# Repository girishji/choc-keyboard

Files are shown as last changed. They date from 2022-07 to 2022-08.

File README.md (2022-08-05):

## Kailh Choc Keyboard with hotswap

A keyboard PCB for Kailh Choc low profile switches using KiCad. PCB has
soldering holes for Blackpill (STM32F401) and Adafruit IS31FL3731 breakout
board.

- Use 1.2mm thickness pcb (suitable for Choc 1350 hotswap sockets)
- Diodes are SOD-123 (1N4148)
- LED is SMD 6028 monochrome (you can get white ones from aliexpress). They are
  connected through charlieplex using IS31FL3731 LED driver (Adafruit's
  breakout board). 
- IS31FL3731 drives (PWM) LEDs at 8k Hz. This may cause audible buzz from the
  ceramic capacitors on board of Adafruit board when driven full power. To
  remove noise replace the 2 10uF capacitors on the Adafruit board with
  tantalum capacitors. Alternately, set maximum intensity of LEDs to a value of
  100 (max is 256) in QMK.
- MCU is STM32F401 (Blackpill). See the schematic for row/column connections.
  This MCU comes with USB-C.
- QMK code for this keyboard is on
  [github](https://github.com/girishji/qmk_firmware/tree/girish_dev_branch/keyboards/chockb/rev1)
- Switch plate with cutouts for switches is in switch-plate directory; If you are
  using jlcpcb, have it made with 1.2mm pcb; preferably in aluminum since it holds
  the switches better.
- There are gerber files for jlcpcb; Compress them into a zip file and upload
  it to jlcpcb

front side
back side
3d printed case
3d printed case

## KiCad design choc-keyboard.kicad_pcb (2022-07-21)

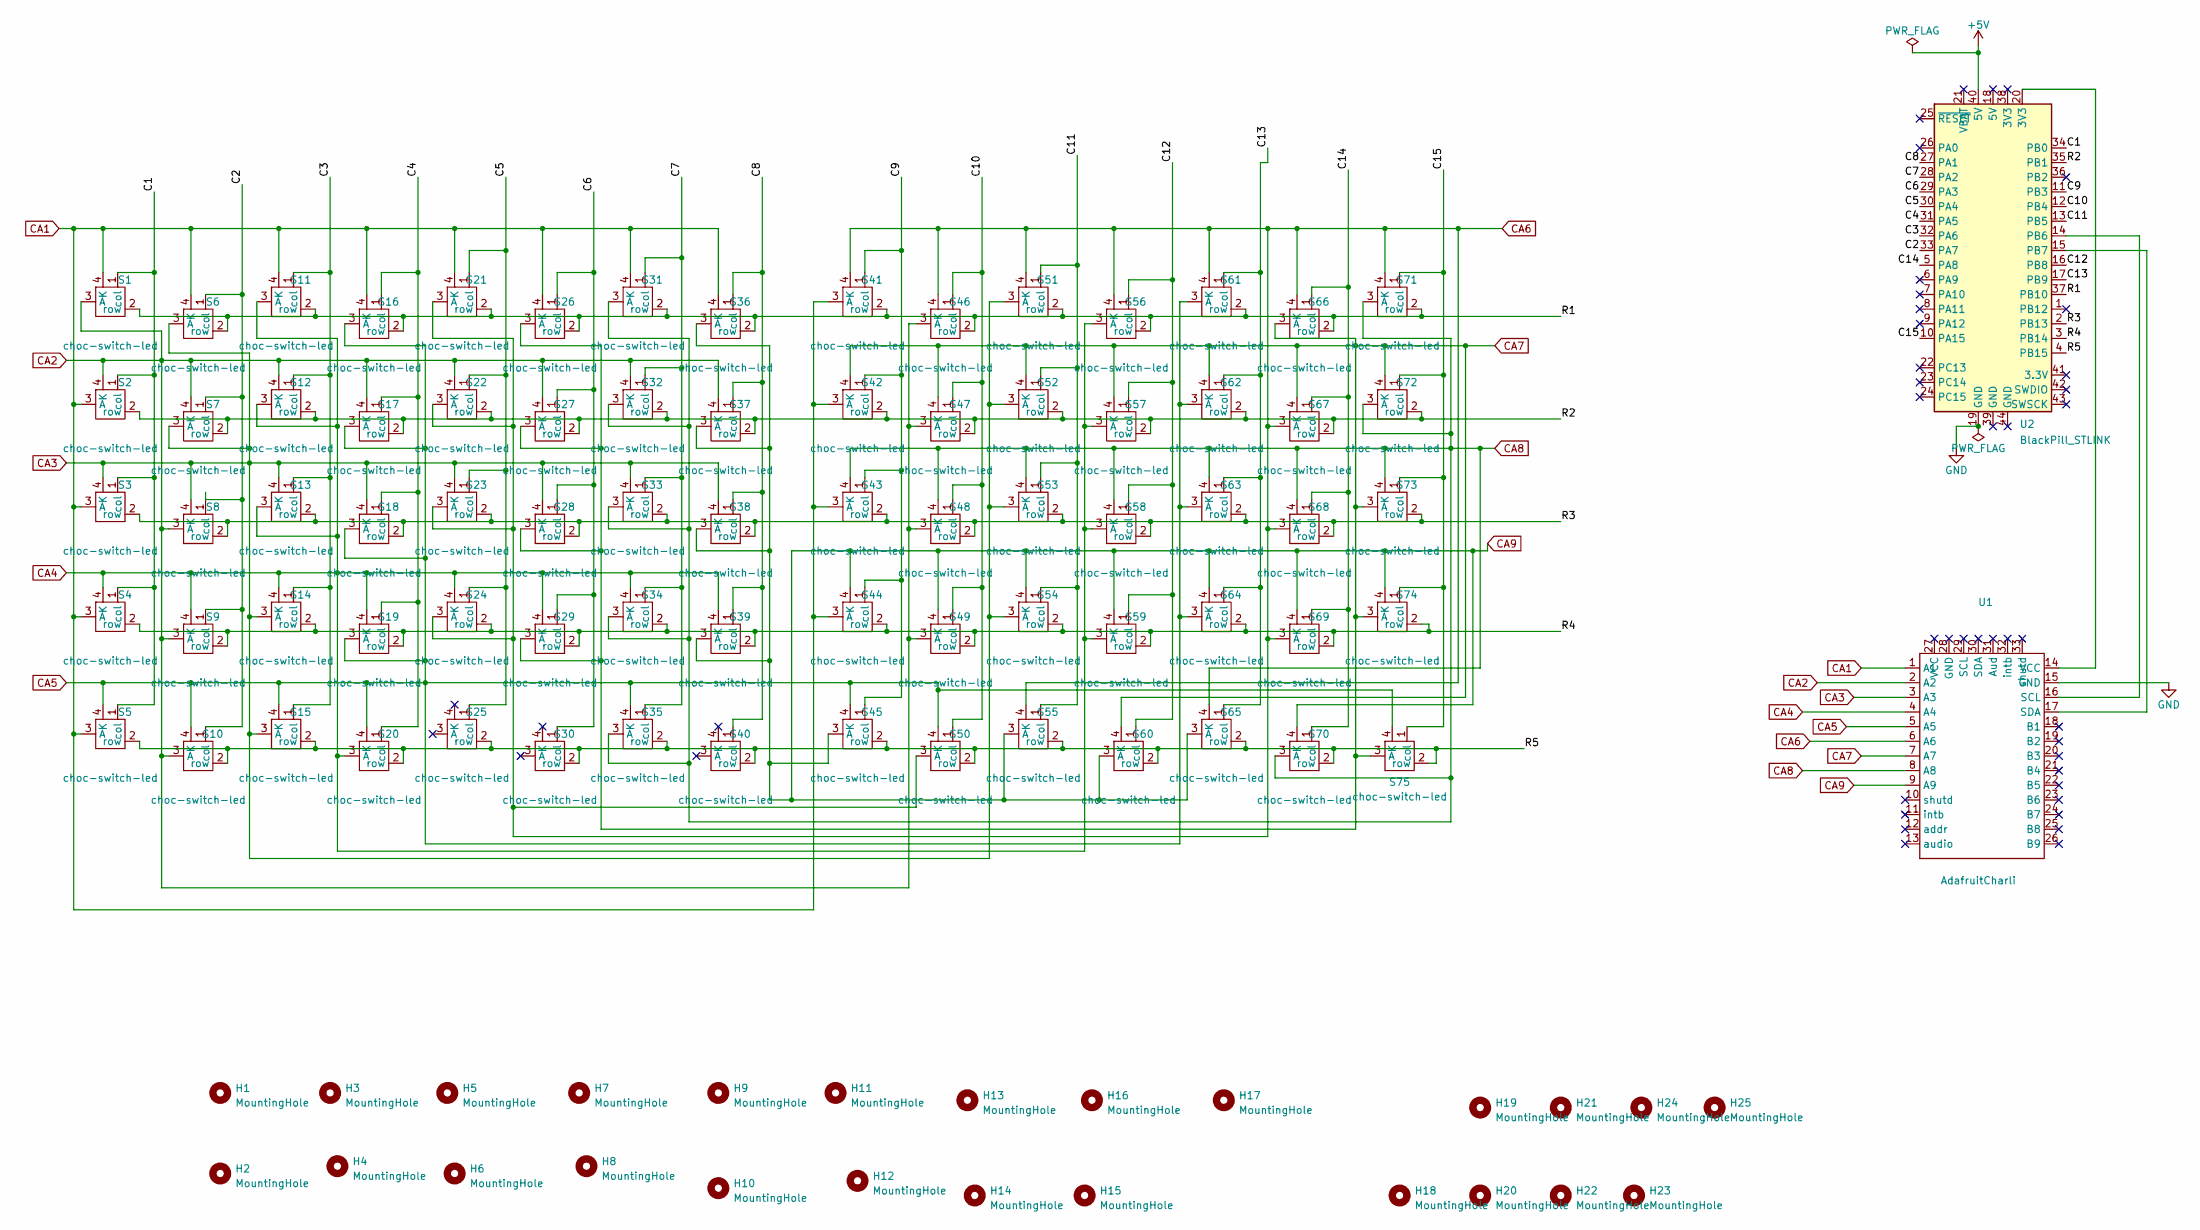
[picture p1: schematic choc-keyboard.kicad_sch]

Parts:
H1, H2, H3, H4, H5, H6, H7, H8, H9, H10, H11, H12, H13, H14, H15, H16, H17: MountingHole; MountingHole_2.2mm_M2_jlcpcb
H18, H19, H20, H21, H22, H23, H24, H25: MountingHole; TestPoint_Plated_Hole_D1.2mm
S1, S3, S4, S5, S6, S7, S8, S9, S10, S11, S12, S13, S14, S15, S16, S17, S18, S19, S20, S21, S22, S23, S24, S25, S26, S27, S28, S29, S30, S31, S32, S33, S34, S35, S36, S37, S38, S39, S40, S41, S42, S43, S44, S45, S46, S47, S48, S49, S50, S51, S52, S53, S54, S55, S56, S57, S58, S59, S60, S61, S62, S63, S64, S65, S66, S67, S68, S69, S70, S71, S72, S73, S74, S75: choc-switch-led; SW_Hotswap_Kailh_Choc
S2: choc-switch-led; SW_Hotswap_Kailh_Choc_noLed
U1: AdafruitCharli; AdafruitCharliplex
U2: BlackPill_STLINK

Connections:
+5V: U2.40 (5V)
/C1: S1.1 (col), S2.1 (col), S3.1 (col), S4.1 (col), S5.1 (col), U2.34 (PB0)
/C2: S6.1 (col), S7.1 (col), S8.1 (col), S9.1 (col), S10.1 (col), U2.33 (PA7)
/C3: S11.1 (col), S12.1 (col), S13.1 (col), S14.1 (col), S15.1 (col), U2.32 (PA6)
/C4: S16.1 (col), S17.1 (col), S18.1 (col), S19.1 (col), S20.1 (col), U2.31 (PA5)
/C5: S21.1 (col), S22.1 (col), S23.1 (col), S24.1 (col), S25.1 (col), U2.30 (PA4)
/C6: S26.1 (col), S27.1 (col), S28.1 (col), S29.1 (col), S30.1 (col), U2.29 (PA3)
/C7: S31.1 (col), S32.1 (col), S33.1 (col), S34.1 (col), S35.1 (col), U2.28 (PA2)
/C8: S36.1 (col), S37.1 (col), S38.1 (col), S39.1 (col), S40.1 (col), U2.27 (PA1)
/C9: S41.1 (col), S42.1 (col), S43.1 (col), S44.1 (col), S45.1 (col), U2.11 (PB3)
/C10: S46.1 (col), S47.1 (col), S48.1 (col), S49.1 (col), S50.1 (col), U2.12 (PB4)
/C11: S51.1 (col), S52.1 (col), S53.1 (col), S54.1 (col), S55.1 (col), U2.13 (PB5)
/C12: S56.1 (col), S57.1 (col), S58.1 (col), S59.1 (col), S60.1 (col), U2.16 (PB8)
/C13: S61.1 (col), S62.1 (col), S63.1 (col), S64.1 (col), S65.1 (col), U2.17 (PB9)
/C14: S66.1 (col), S67.1 (col), S68.1 (col), S69.1 (col), S70.1 (col), U2.5 (PA8)
/C15: S71.1 (col), S72.1 (col), S73.1 (col), S74.1 (col), S75.1 (col), U2.10 (PA15)
/R1: S1.2 (row), S6.2 (row), S11.2 (row), S16.2 (row), S21.2 (row), S26.2 (row), S31.2 (row), S36.2 (row), S41.2 (row), S46.2 (row), S51.2 (row), S56.2 (row), S61.2 (row), S66.2 (row), S71.2 (row), U2.37 (PB10)
/R2: S2.2 (row), S7.2 (row), S12.2 (row), S17.2 (row), S22.2 (row), S27.2 (row), S32.2 (row), S37.2 (row), S42.2 (row), S47.2 (row), S52.2 (row), S57.2 (row), S62.2 (row), S67.2 (row), S72.2 (row), U2.35 (PB1)
/R3: S3.2 (row), S8.2 (row), S13.2 (row), S18.2 (row), S23.2 (row), S28.2 (row), S33.2 (row), S38.2 (row), S43.2 (row), S48.2 (row), S53.2 (row), S58.2 (row), S63.2 (row), S68.2 (row), S73.2 (row), U2.2 (PB13)
/R4: S4.2 (row), S9.2 (row), S14.2 (row), S19.2 (row), S24.2 (row), S29.2 (row), S34.2 (row), S39.2 (row), S44.2 (row), S49.2 (row), S54.2 (row), S59.2 (row), S64.2 (row), S69.2 (row), S74.2 (row), U2.3 (PB14)
/R5: S5.2 (row), S10.2 (row), S15.2 (row), S20.2 (row), S25.2 (row), S30.2 (row), S35.2 (row), S40.2 (row), S45.2 (row), S50.2 (row), S55.2 (row), S60.2 (row), S65.2 (row), S70.2 (row), S75.2 (row), U2.4 (PB15)
CA1: S1.4 (K), S2.3 (A), S3.3 (A), S4.3 (A), S5.3 (A), S6.4 (K), S11.4 (K), S16.4 (K), S21.4 (K), S26.4 (K), S31.4 (K), S36.4 (K), S41.3 (A), S42.3 (A), S43.3 (A), S44.3 (A), U1.1 (A1)
CA2: S1.3 (A), S2.4 (K), S7.4 (K), S8.3 (A), S9.3 (A), S10.3 (A), S12.4 (K), S17.4 (K), S22.4 (K), S27.4 (K), S32.4 (K), S37.4 (K), S46.3 (A), S47.3 (A), S48.3 (A), S49.3 (A), U1.2 (A2)
CA3: S3.4 (K), S6.3 (A), S7.3 (A), S8.4 (K), S13.4 (K), S14.3 (A), S15.3 (A), S18.4 (K), S23.4 (K), S28.4 (K), S33.4 (K), S38.4 (K), S51.3 (A), S52.3 (A), S53.3 (A), S54.3 (A), U1.3 (A3)
CA4: S4.4 (K), S9.4 (K), S11.3 (A), S12.3 (A), S13.3 (A), S14.4 (K), S19.4 (K), S20.3 (A), S24.4 (K), S29.4 (K), S34.4 (K), S39.4 (K), S56.3 (A), S57.3 (A), S58.3 (A), S59.3 (A), U1.4 (A4)
CA5: S5.4 (K), S10.4 (K), S15.4 (K), S16.3 (A), S17.3 (A), S18.3 (A), S19.3 (A), S20.4 (K), S35.4 (K), S45.4 (K), S50.4 (K), S61.3 (A), S62.3 (A), S63.3 (A), S64.3 (A), S75.4 (K), U1.5 (A5)
CA6: S21.3 (A), S22.3 (A), S23.3 (A), S24.3 (A), S41.4 (K), S46.4 (K), S50.3 (A), S51.4 (K), S55.4 (K), S56.4 (K), S61.4 (K), S66.4 (K), S67.3 (A), S68.3 (A), S69.3 (A), S71.4 (K), U1.6 (A6)
CA7: S26.3 (A), S27.3 (A), S28.3 (A), S29.3 (A), S42.4 (K), S47.4 (K), S52.4 (K), S57.4 (K), S60.4 (K), S62.4 (K), S66.3 (A), S67.4 (K), S72.4 (K), S73.3 (A), S74.3 (A), S75.3 (A), U1.7 (A7)
CA8: S31.3 (A), S32.3 (A), S33.3 (A), S34.3 (A), S35.3 (A), S43.4 (K), S48.4 (K), S53.4 (K), S58.4 (K), S63.4 (K), S65.4 (K), S68.4 (K), S70.3 (A), S71.3 (A), S72.3 (A), S73.4 (K), U1.8 (A8)
CA9: S36.3 (A), S37.3 (A), S38.3 (A), S39.3 (A), S44.4 (K), S45.3 (A), S49.4 (K), S54.4 (K), S55.3 (A), S59.4 (K), S60.3 (A), S64.4 (K), S65.3 (A), S69.4 (K), S70.4 (K), S74.4 (K), U1.9 (A9)
GND: U1.15 (GND), U2.19 (GND)
unnamed: U1.14 (VCC), U2.20 (3V3)
unnamed: U1.16 (SCL), U2.14 (PB6)
unnamed: U1.17 (SDA), U2.15 (PB7)

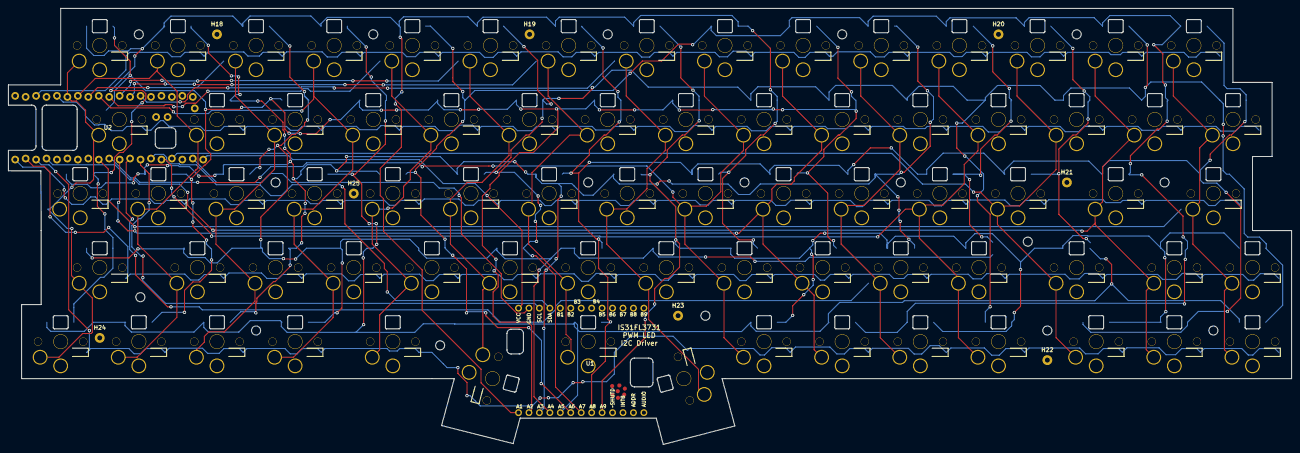
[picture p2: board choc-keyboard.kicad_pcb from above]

Board: 2 copper layers, 311.9 x 106.0 mm, 102 parts (0 on the bottom side), 33 nets.

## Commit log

2022-07-14 First commit
    M .gitignore
    M README.md
    A choc-keyboard.kicad_pcb
    A choc-keyboard.kicad_prl
    A choc-keyboard.kicad_pro
    A choc-keyboard.kicad_sch
    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
    [choc-keyboard.kicad_pcb, choc-keyboard.kicad_sch]
2022-07-21 updated footprints
    M choc-keyboard.kicad_pcb
    M choc-keyboard.kicad_prl
    M choc-keyboard.kicad_pro
    M choc-keyboard.kicad_sch
    M placesw.py
    A switch-plate/.gitignore
    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
    [choc-keyboard.kicad_pcb, choc-keyboard.kicad_sch, switch-plate.kicad_pcb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]
2022-08-05 Add gerber files
    A jlcpcb/gerber/choc-keyboard-B_Cu.gbl
    A jlcpcb/gerber/choc-keyboard-B_Mask.gbs
    A jlcpcb/gerber/choc-keyboard-B_Paste.gbp
    A jlcpcb/gerber/choc-keyboard-B_Silkscreen.gbo
    A jlcpcb/gerber/choc-keyboard-Edge_Cuts.gm1
    A jlcpcb/gerber/choc-keyboard-F_Cu.gtl
    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
    [choc-keyboard-B_Cu.gbl, choc-keyboard-B_Mask.gbs, choc-keyboard-B_Paste.gbp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]
